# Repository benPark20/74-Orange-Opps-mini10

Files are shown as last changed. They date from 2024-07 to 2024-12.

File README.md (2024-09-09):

# 74-Orange-Opps

## We are Team 74 of mini FRC, the Orange Opps.

Shooting Speaker

Our rookie season 2024 was great! You can watch [the stream of the event](https://www.youtube.com/watch?v=baMjMV4FzJ8) but it is really long so i would reccomend if you want to see to watch [match 17](https://youtu.be/baMjMV4FzJ8?t=8170) (*we are the middle one on blue alliance*). Here are some of our accomplishments at Mini FRC 10:
- Our alliance made it to the semifinals in the losers bracket in a double elimintaion tournement (*That's 3rd Place!*),
- We managed to be the first, and one of the only, team to successfully climb on the stage,
- and we had the cleanest looking robot ~~*biased*~~.

## Design

We designed our robot heavily off of the robot that our team's team had competed and made worlds with for regular, full-sized FRC. Our workflow was in OnShape so you can [easily view and download/3D print CAD here](https://cad.onshape.com/documents/561065ee11688eb6314d06ba/w/829a4e28d8331633d6eed549/e/7dac9a85c5c0d4fed6ff8528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).

Robot CAD
*pretend that those are mechanum wheels (it's a pain to deal with them in cad)*

## Assembly

Assembly of the robot was fairly straight forward since we CAD to go off of, but we did need a lot of parts and a lot of testing testing shooter.
This is a quick BOM, the total cost adds up to around $70 and it was split between the four people on our team
| Item | Quantity |
| :--- | :---: |
| ESP32 | 1 |
| Alfredo NoU2 | 1 |
| [9V Battery](https://www.alfredosys.com/news/fun-facts-about-batteries/)* | 1 |
| Mechanum Wheels | 4 |
| TT Motor + gearbox| 4 |
| TT Motor | 2 |
| n20 Motor | 2 |
| 50g servo | 1 |
| Grip Tape | 1 |
| Wires | 1 |

## Code

Our code is based in Arduino IDE and runs on an ESP32 connected to a [NoU2 board](https://www.alfredosys.com/products/alfredo-nou2/) though we have plans to upgrade to a NoU3 when it comes out. I have been working with the code to implement an ultrasonic sensor that can detect how far away our robot is from the stage so that it can automatically aim and shoot from any point on our wing with no obstruction.

## How can you do the same

This was only possible with the help of [Alfredo Systems](https://www.alfredosys.com) and the wonderful program that they are running. I you want to just buy parts and make your own then go for it, but if you are wanting to hold a competition for you and your community then reach out to them on their website! They provide all the resources you would ever need to hold one of these. It is a great outreach opportunity and really a fun event all around.

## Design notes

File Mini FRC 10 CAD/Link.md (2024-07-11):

# [Link to OnShape Document](https://cad.onshape.com/documents/561065ee11688eb6314d06ba/w/829a4e28d8331633d6eed549/e/dabec9b53802dcae05636834)

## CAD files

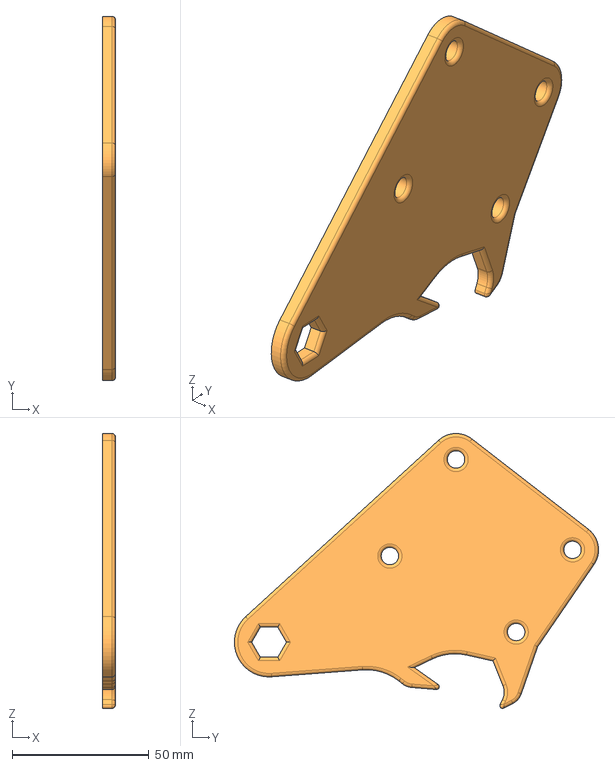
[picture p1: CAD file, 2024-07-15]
Mini FRC 10 CAD/Master Part Studio - Plate 1.step
4.76 x 133.3 x 100.7 mm

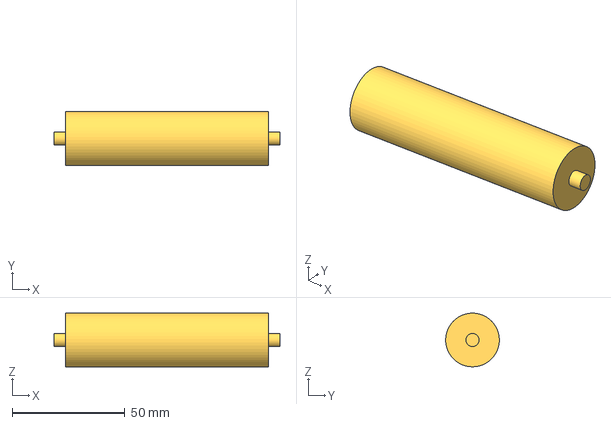
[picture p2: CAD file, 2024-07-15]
Mini FRC 10 CAD/Master Part Studio - Roller 1.step
100.4 x 23.9 x 23.9 mm

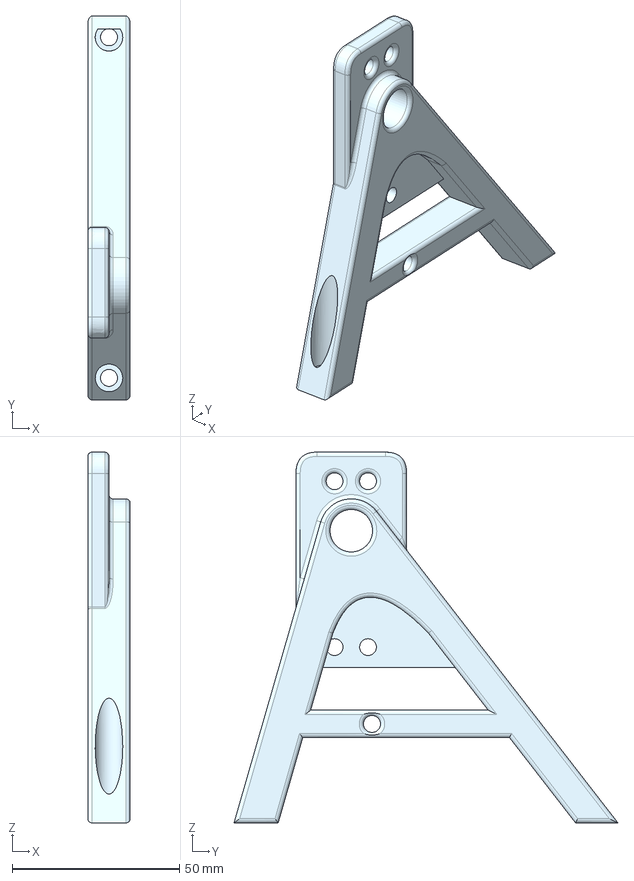
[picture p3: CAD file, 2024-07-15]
Mini FRC 10 CAD/Master Part Studio - A-Frame 2.step
12.7 x 114.8 x 110.8 mm

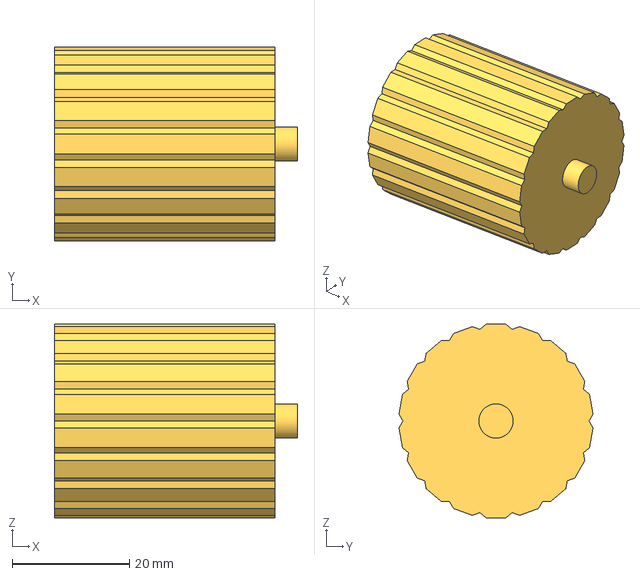
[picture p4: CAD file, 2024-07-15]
Mini FRC 10 CAD/Master Part Studio - Flywheel.step
41.5 x 33.1 x 33.0 mm

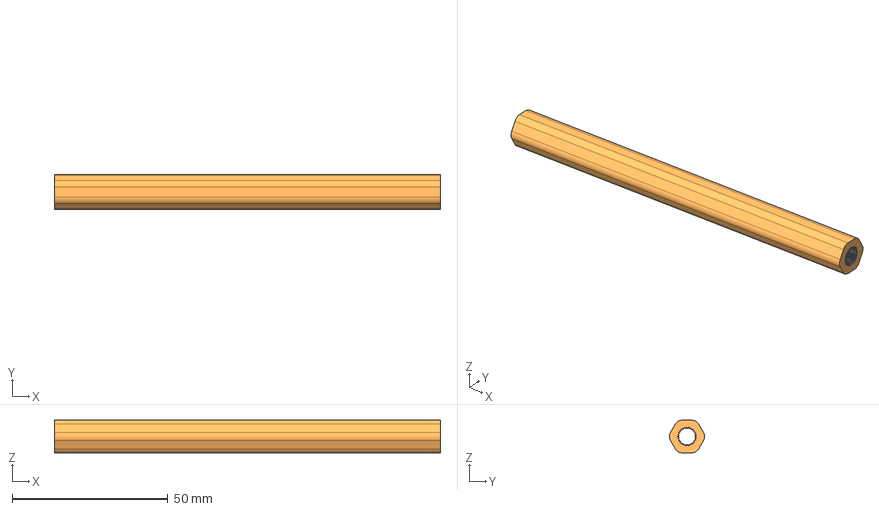
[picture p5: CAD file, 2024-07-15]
Mini FRC 10 CAD/Master Part Studio - Hex.step
123.9 x 11.3 x 10.5 mm

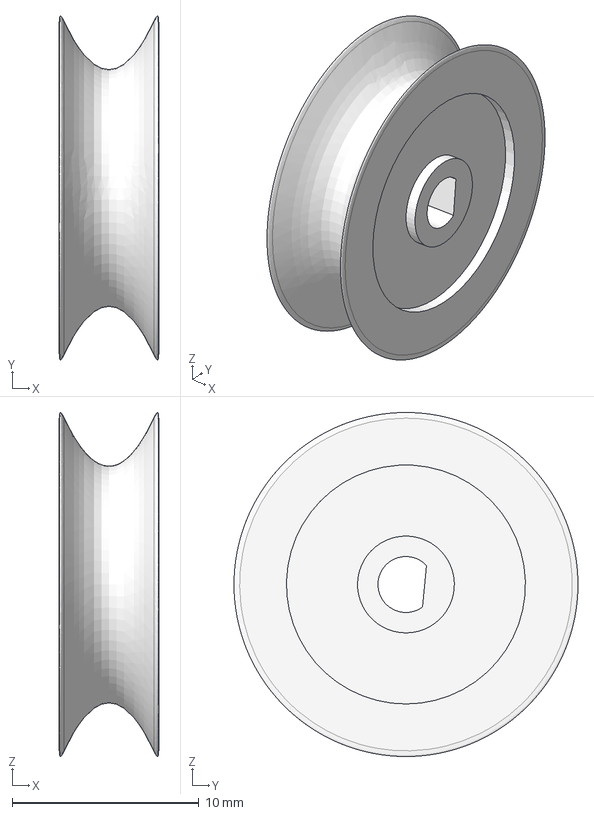
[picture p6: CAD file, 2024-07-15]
Mini FRC 10 CAD/Master Part Studio - Intake Pulley.step
5.33 x 18.4 x 18.4 mm

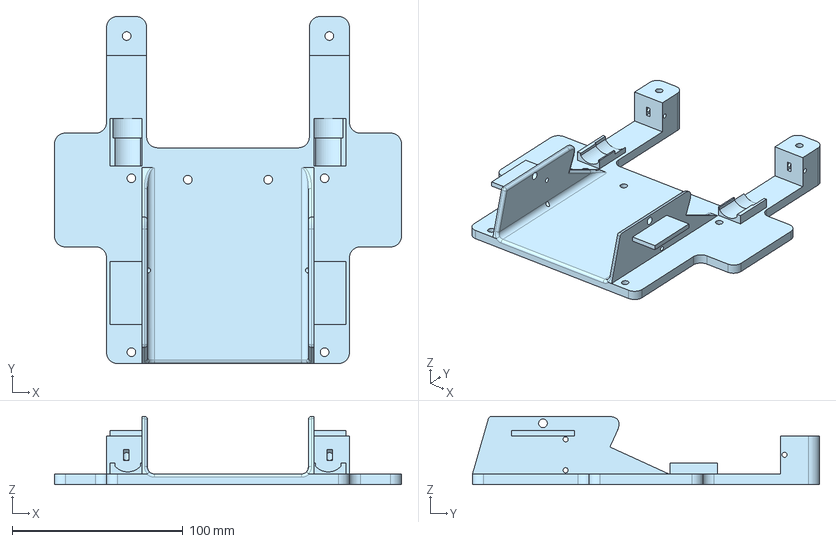
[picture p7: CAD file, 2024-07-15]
Mini FRC 10 CAD/Master Part Studio - Chassis.step
203.2 x 203.2 x 40.0 mm

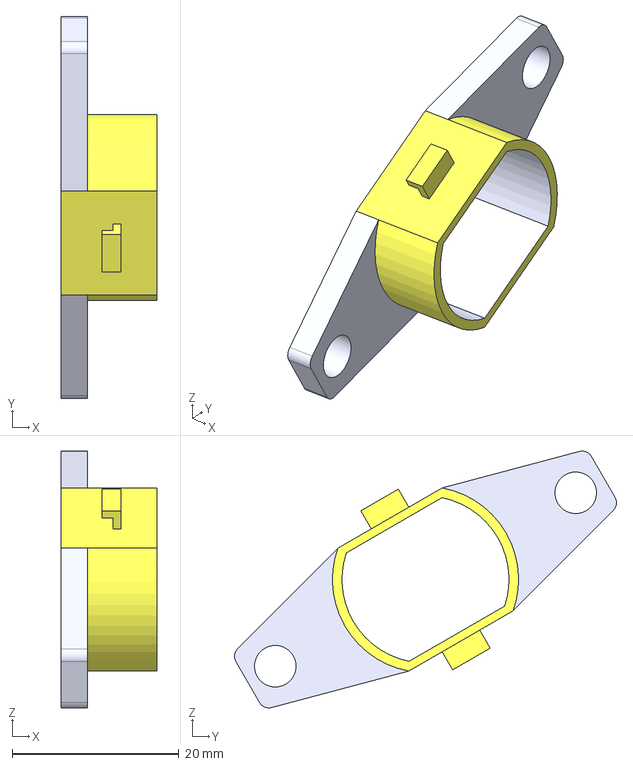
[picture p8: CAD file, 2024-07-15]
Mini FRC 10 CAD/Master Part Studio - Motor-Mount.step
11.5 x 45.8 x 30.8 mm

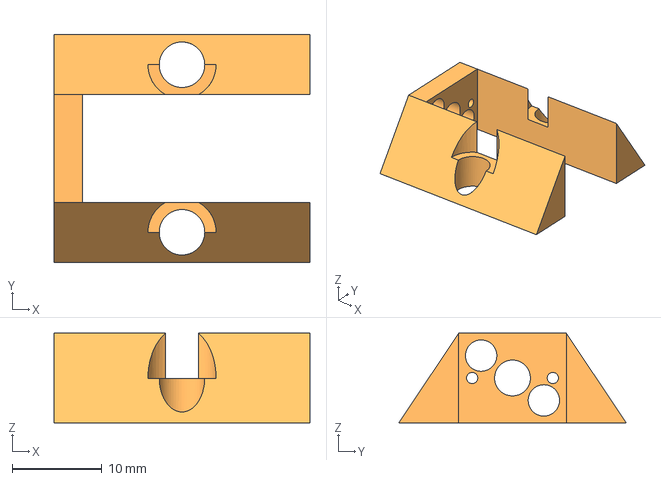
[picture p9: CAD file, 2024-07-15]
Mini FRC 10 CAD/Master Part Studio - Intake Motor Mount.step
28.6 x 25.4 x 10.0 mm

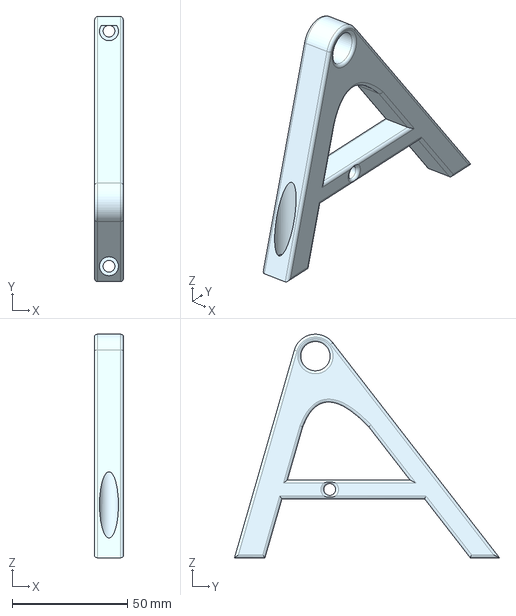
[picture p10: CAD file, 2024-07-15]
Mini FRC 10 CAD/Master Part Studio - A-Frame 1.step
12.7 x 114.8 x 96.9 mm

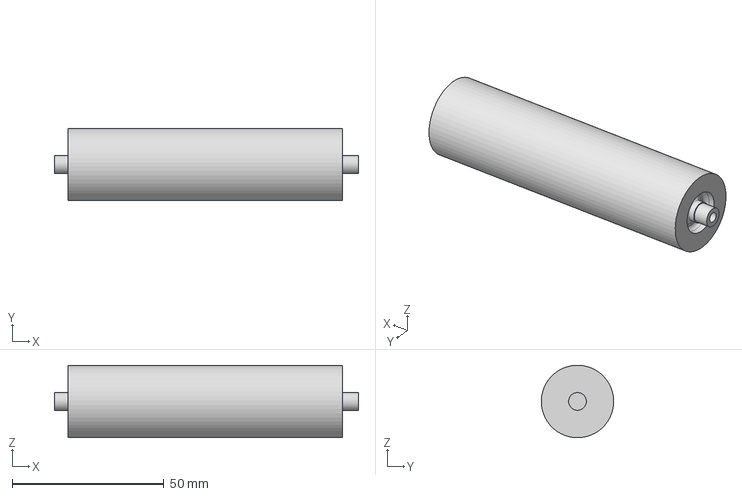
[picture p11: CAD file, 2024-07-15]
Mini FRC 10 CAD/Master Part Studio - Roller 2.step
100.2 x 23.9 x 23.9 mm

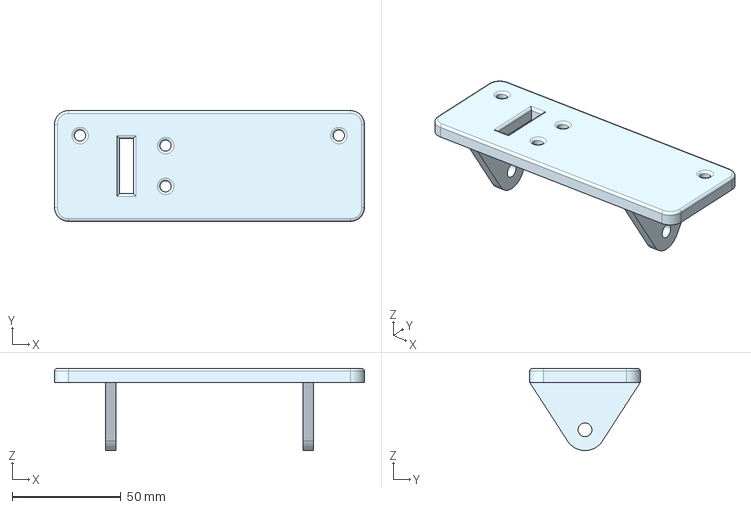
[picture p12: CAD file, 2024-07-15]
Mini FRC 10 CAD/Master Part Studio - Intake Plate.step
142.2 x 50.8 x 37.7 mm

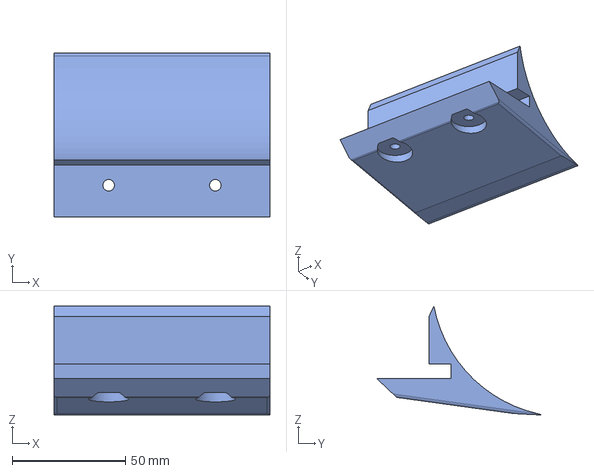
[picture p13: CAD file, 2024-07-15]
Mini FRC 10 CAD/Master Part Studio - Scoop.step
95.2 x 72.5 x 48.0 mm

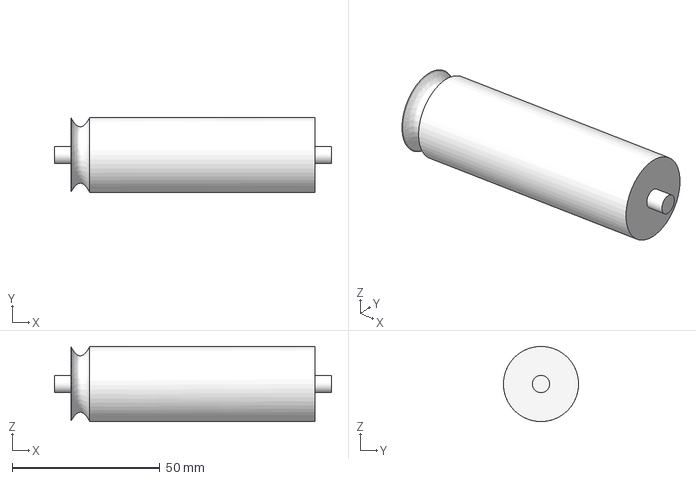
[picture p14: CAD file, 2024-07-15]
Mini FRC 10 CAD/Master Part Studio - Intake Roller.step
93.7 x 25.4 x 25.4 mm

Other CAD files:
Mini FRC 10 CAD/Master Part Studio - Plate 2.step
Mini FRC 10 CAD/Master Part Studio - Hex Spacer.step
Mini FRC 10 CAD/Intake+drivetrain V1.stl

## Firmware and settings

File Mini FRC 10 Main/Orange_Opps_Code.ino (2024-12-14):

#include <PestoLink-Receive.h>
#include <Alfredo_NoU2.h>
#include <NewPing.h>

// Button definitions
#define BUTTON_BOTTOM 0
#define BUTTON_RIGHT 1
#define BUTTON_LEFT 2
#define BUTTON_TOP 3
#define LEFT_BUMPER 4
#define RIGHT_BUMPER 5
#define LEFT_TRIGGER 6
#define RIGHT_TRIGGER 7
#define MID_RIGHT 8
#define MID_LEFT 9
#define L_PRESS 10
#define R_PRESS 11
#define D_UP 12
#define D_DOWN 13
#define D_LEFT 14
#define D_RIGHT 15

// Motor and servo definitions
NoU_Motor frontLeftMotor(1); 
NoU_Motor frontRightMotor(2);
NoU_Motor rearLeftMotor(3);
NoU_Motor rearRightMotor(4);
NoU_Motor indexerMotor(5); // Intake/indexer motor
NoU_Motor shooterMotor(6); // Shooter motor
NoU_Servo servo(1);        // Aiming servo

// Drivetrain setup
NoU_Drivetrain drivetrain(&frontLeftMotor, &frontRightMotor, &rearLeftMotor, &rearRightMotor);

// Distance sensor setup
#define TRIGGER_PIN 25
#define ECHO_PIN 26
#define MAX_DISTANCE 400
NewPing sonar(TRIGGER_PIN, ECHO_PIN, MAX_DISTANCE);

// Variables
int distance = 0;         // Distance measured to subwoofer
int measurements = 0;       // Number of measurements taken
int servoAngle = 0;         // Servo angle for aiming
float indexerThrottle = 0;
float shooterThrottle = 0;

// Time tracking for auto mode
long AUTO_START_TIME = 0;
long SHOOTER_START_TIME = 0;

// Enum for robot states (manual or auto mode)
enum State { MANUAL, AUTO };
State ROBOT_STATE;

void setup() {
  PestoLink.begin("Clementiny");  // Name your robot here
  Serial.begin(9600);
  Serial.println("Start");
  
  // Invert motors if necessary
  frontLeftMotor.setInverted(true);
  frontRightMotor.setInverted(false);
  rearLeftMotor.setInverted(true);
  rearRightMotor.setInverted(false);
  shooterMotor.setInverted(true);
  indexerMotor.setInverted(false);

  // Initialize robot state to manual
  ROBOT_STATE = MANUAL;
}

void loop() {
  // Update connection status and handle robot states
  if (PestoLink.update()) {
    if (ROBOT_STATE == MANUAL) {
      handleManualMode();
      PestoLink.print("Teleop", "0x32a852");
    } else {
      handleAutoMode();
      PestoLink.print("Auto", "0x36a0d1" );
    }
    RSL::setState(RSL_ENABLED);
  } else {
    RSL::setState(RSL_DISABLED);
  }
  // No need to modify this
  RSL::update();
}

// Handle manual driving and shooting
void handleManualMode() {

  // Start auto mode if button is pressed
  if (PestoLink.buttonHeld(MID_LEFT)) {
    ROBOT_STATE = AUTO;
    AUTO_START_TIME = millis();
    return;
  }

  // Driving controls
  float xVelocity = PestoLink.getAxis(0);
  float yVelocity = -PestoLink.getAxis(1);
  float rotation = PestoLink.getAxis(2);
  drivetrain.holonomicDrive(xVelocity, yVelocity, rotation);

  // Servo adjustment based on distance to subwoofer (when button pressed)
  if (PestoLink.buttonHeld(BUTTON_LEFT)) {
    updateDistanceAndServo();
  }

  // Manual servo control
  manualServoControl();

  // Motor control for indexer and shooter
  handleIndexerAndShooter();
  
  // Apply motor throttle
  indexerMotor.set(indexerThrottle);
  shooterMotor.set(shooterThrottle);

  // Apply Servo Angle
  servo.write(servoAngle);
}

// Handle servo control using distance sensor
void updateDistanceAndServo() {
  if (measurements < 50) {
    int distance = sonar.ping_cm();// Get distance in cm
    int trash = sonar.ping_cm();
    measurements++;
    
    if (distance != 0.00) {
      // Tune distance offset as needed
      distance += -2;
      if(distance <= 0){distance = 0;}

      // Set servo angle based on distance using a regression function or lookup table
      servoAngle = calculateServoAngleFromDistance(distance);  // Use regression data here
      char buffer[64];
      sprintf(buffer, "Distance: %i || Angle: %i", distance, servoAngle);
      PestoLink.printToTerminal(buffer);
    }
  }
}

// Function to calculate servo angle from distance using regression model
int calculateServoAngleFromDistance(float distance) {

  int x = distance;
  float a = -7705.458;
  float b = 0.97141;
  float c = -104.09;
  float d = 97.8772;

  float angle = (a * (b / (x - c)) + d);

  float A = 1.13565;
  float B = 0.302267;
  float C = -1.58807;
  float D = -0.128382;

  angle += (A * cos(B * x + C) + D);
  
  // Clamp the angle to a valid range for your servo
  if (angle < 0) angle = 0;
  if (angle > 180) angle = 180;

  return angle;
}


// Manual servo control using joystick or buttons'
int lastA = -1;

void manualServoControl() {
  if (PestoLink.buttonHeld(D_DOWN) && servoAngle > 0) {
    servoAngle -= 1;
    delay(100);
    char buffer[64];
    sprintf(buffer, "Angle: %i", servoAngle);
    PestoLink.printToTerminal(buffer);
  }
  if (PestoLink.buttonHeld(D_UP) && servoAngle < 180){
    servoAngle += 1;
    delay(100);
    char buffer[64];
    sprintf(buffer, "Angle: %i", servoAngle);
    PestoLink.printToTerminal(buffer);
  }
  if(PestoLink.buttonHeld(BUTTON_BOTTOM)){
    servoAngle = 120;//amp
    PestoLink.printToTerminal("Amp Angle");
  }
  else if(PestoLink.buttonHeld(BUTTON_RIGHT)){
    servoAngle = 80;//pass
    PestoLink.printToTerminal("Passing Angle");
  }
  else if(PestoLink.buttonHeld(R_PRESS)){
    updateDistanceAndServo();
  }

  if(servoAngle != lastA){
    lastA = servoAngle;
  }
}

// Handle the indexer and shooter motors
void handleIndexerAndShooter() {
  // Control the indexer (intake) motor
  if (PestoLink.buttonHeld(LEFT_BUMPER)) {
    indexerThrottle = 1;  // Intake forward
    servoAngle = 0;
    PestoLink.printToTerminal("Intaking. . .");
  } else if (PestoLink.buttonHeld(LEFT_TRIGGER)) {
    indexerThrottle = -1; // Intake reverse
  } else {
    indexerThrottle = 0;  // Stop intake
  }
  
  // Control the shooter motor
  if (PestoLink.buttonHeld(RIGHT_TRIGGER)) {
    shooterThrottle = 1; // Spin shooter motor to shoot
    SHOOTER_START_TIME = millis();
    updateDistanceAndServo();
  } else if(PestoLink.buttonHeld(RIGHT_BUMPER)){
    servoAngle = 25;
    shooterThrottle = 1;
    SHOOTER_START_TIME = millis();
  } else if(PestoLink.buttonHeld(BUTTON_TOP)){
    shooterThrottle = 1;
    SHOOTER_START_TIME = millis();
  } else if(PestoLink.buttonHeld(LEFT_BUMPER) || PestoLink.buttonHeld(LEFT_TRIGGER)){
    shooterThrottle = -1;
  } else {
    shooterThrottle = 0;
  }

  // Reset measurments
  if(PestoLink.buttonHeld(BUTTON_LEFT)){
    measurements = 0;
  }

  // Timing for indexer based on shooting
  handleShooterTiming();
}

// Handle timing for shooter and indexer motors
void handleShooterTiming() {
  if (SHOOTER_START_TIME != 0 ) {
    unsigned long currentTime = millis();
    unsigned long elapsedTime = currentTime - SHOOTER_START_TIME;

    if (elapsedTime > 100 && elapsedTime <= 1200) {
      indexerThrottle = 1;  // Run indexer during shoot
      shooterThrottle = 0.7;
      PestoLink.printToTerminal("Shots Fired!");
    } else if (elapsedTime > 1200 && elapsedTime < 1400) {
      measurements = 0;
      shooterThrottle = -1;
    } else if (elapsedTime >= 1400) {
      resetMotors();
      SHOOTER_START_TIME = 0; // Reset after the shoot sequence
      return;
    }
  }
}

float TSA = 0;
// Handle auto mode actions
void handleAutoMode() {
  if (PestoLink.buttonHeld(MID_RIGHT)) {
    ROBOT_STATE = MANUAL;
    return;
  }
  TSA = (millis() - AUTO_START_TIME);
    if(TSA < 14000){
      if(TSA < 1000){ //aim and spin up shooter
        servo.write(33);//subwoofer angle
        shooterMotor.set(1);
      }
      if(TSA > 1000 && TSA < 1500){ //shoot
        indexerMotor.set(1);
      }
      if(TSA > 1500 && TSA < 2000){//reset motor
        resetMotors();
      }
      if(TSA > 2100 && TSA < 2200){//reset servo
        servo.write(0);
      }
      if(TSA > 2500 && TSA < 4000){//intake
        indexerMotor.set(1);
        shooterMotor.set(-1);
        if(TSA > 2600 && TSA < 3100/*change for distance*/){
          drivetrain.arcadeDrive(1, 0);
        } else{
          drivetrain.arcadeDrive(0, 0);
        }
      }
      if(TSA > 4000 && TSA < 4250){//reset motor
        resetMotors();
      }
      if(TSA > 4000 && TSA < 4500/*change for distance*/){//drive to subwoofer
        drivetrain.arcadeDrive(-1, 0);
      }
      if(TSA > 4500 && TSA < 5600){//stop
        drivetrain.arcadeDrive(0,0);
      }
      if(TSA > 5600 && TSA < 7000){ //aim and spin up shooter
        drivetrain.arcadeDrive(0, 0);
        servo.write(33);//subwoofer angle
        shooterMotor.set(1);
      }
      if(TSA > 7000 && TSA < 7500){ //shoot
        indexerMotor.set(1);
      }
      if(TSA > 7500 && TSA < 8000){//reset motor
        resetMotors();
      }
      if(TSA > 8000){//reset servo
        servo.write(0);
      }
    }
    else {
      drivetrain.arcadeDrive(0, 0);
      return;      
    }
}

// Reset motors (shooter and indexer)
void resetMotors() {
  shooterMotor.set(0);
  indexerMotor.set(0);
}

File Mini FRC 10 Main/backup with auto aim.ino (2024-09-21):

/*
TIPS FOR TUNING!
when axle is positioned right
Servo minimum is -20
Servo maximum is 130
Motors dont work until 0.6 to 0.7

*/


#include <PestoLink-Receive.h>
#include <Alfredo_NoU2.h>
#include <NewPing.h>

// If your robot has more than a drivetrain and one servo, add those actuators here 
NoU_Motor frontLeftMotor(1); 
NoU_Motor frontRightMotor(2);
NoU_Motor rearLeftMotor(3);
NoU_Motor rearRightMotor(4);
NoU_Motor indexerMotor(5);
NoU_Motor shooterMotor(6);
NoU_Servo servo(1);

// This creates the drivetrain object, you shouldn't have to mess with this
NoU_Drivetrain drivetrain(&frontLeftMotor, &frontRightMotor, &rearLeftMotor, &rearRightMotor);

//distance sensor
#define TRIGGER_PIN 25
#define ECHO_PIN 26
#define MAX_DISTANCE 400

NewPing sonar(TRIGGER_PIN, ECHO_PIN, MAX_DISTANCE);

float distance;
float TSA;
int measurements;
// This lets us easily keep track of whether the robot is in auto mode or not.
// Experiment with adding more modes!
enum State { MANUAL, AUTO };

// These are the buttons we look for.
int AUTO_START_BUTTON = 8;
int AUTO_CANCEL_BUTTON = 9;

// This stores the time at which we started auto mode. This lets us keep track of how long we've been in auto mode for.
long AUTO_START_TIME = 0;
long SHOOTER_START_TIME = 0;
State ROBOT_STATE;

void setup() {
  //EVERYONE SHOULD CHANGE "ESP32 Bluetooth" TO THE NAME OF THEIR ROBOT
  PestoLink.begin("CallingAllBluds");
  Serial.begin(9600);
  // If a motor in your drivetrain is spinning the wrong way, change the value for it here from 'false' to 'true'
  frontLeftMotor.setInverted(true);
  frontRightMotor.setInverted(false);
  rearLeftMotor.setInverted(true);
  rearRightMotor.setInverted(false);

  // No need to mess with this code
  RSL::initialize();
  RSL::setState(RSL_ENABLED);
  ROBOT_STATE = MANUAL;
}

void loop() {
  // Here we define the variables we use in the loop
  float indexerThrottle = 0;
  float shooterThrottle = 0.1; //this needs tuning
  int servoAngle = 90;
  int AutoAngle;

  //When PestoLink.update() is called, it returns "true" only if the robot is connected to phone/laptop  
  if (PestoLink.update()) {
    if (ROBOT_STATE == MANUAL) {
      // We only want to check manual controls if we're in manual mode!
      if (PestoLink.buttonHeld(AUTO_START_BUTTON)) {
        // If the auto mode button is pressed, we should switch to auto mode.
        ROBOT_STATE = AUTO;
        AUTO_START_TIME = millis();
        return; // We don't want to check the manual controls - we just switched to auto mode! This immediately restarts the loop.
      }
      float xVelocity = PestoLink.getAxis(0) * 1;
      float yVelocity = -PestoLink.getAxis(1) * 1;
      float rotation = PestoLink.getAxis(2) * 1;

      drivetrain.holonomicDrive(xVelocity, yVelocity, rotation);

      // Here we decide what the servo angle will be based on if a button is pressed ()

      // Servo Code:
      if (PestoLink.buttonHeld(12)) {
        servoAngle = 130; //climber up angle/amp
        servo.write(servoAngle);
      } else if (PestoLink.buttonHeld(13)) {
        servoAngle = 29; //subwoofer angle
        servo.write(servoAngle);
      } else if (PestoLink.buttonHeld(15)) {
        servoAngle = 53; //podium
        servo.write(servoAngle);
      } else if (PestoLink.buttonHeld(2)) {
        if(measurements < 50){
          distance = sonar.ping()/10;
          measurements++;
          Serial.println(distance);
          if(distance != 0.00){
            distance += 20; //comment out this line for no subwoofer. 20cm = 8 inches
            AutoAngle = distance/5;
            if(distance > 0.1){
              shooterThrottle = -1;
              AutoAngle = distance/5;
              servoAngle = AutoAngle;
              servo.write(servoAngle);
            }
          }
        }
      }
      //Manual Servo Control
      
      if ((PestoLink.getRawAxis(3)) > 230){
        if (servo.getDegrees() > 0){
          servo.write(servo.getDegrees() - 0.001);
        }
      }

      // Motor Code:
      if (PestoLink.buttonHeld(4)) {
        indexerThrottle = 1;
        servo.write(-0);
      } else if (PestoLink.buttonHeld(6)) {
        indexerThrottle = -1;
      } 
      else {
        indexerThrottle = 0;
      }
      
      if (PestoLink.buttonHeld(5)) {
        shooterThrottle = 1;
      } else if (PestoLink.buttonHeld(0)) {
        shooterThrottle = -1;
        SHOOTER_START_TIME = millis();
      } else if (PestoLink.buttonHeld(7)){
        if(measurements < 50){
          distance = sonar.ping()/10;
          measurements++;
          Serial.println(distance);
          if(distance != 0.00){
            distance += 20; //comment out this line for no subwoofer. 20cm = 8 inches
            AutoAngle = distance/5;
            if(distance > 0.1){
              shooterThrottle = -1;
              AutoAngle = distance/5;
              servoAngle = AutoAngle;
              servo.write(servoAngle);
            }
          }
        }
        shooterThrottle = -1;
        SHOOTER_START_TIME = millis();
      } else if(PestoLink.buttonHeld(3)){
        measurements = 0;
      } else if(PestoLink.buttonHeld(1)){
        //automatic amp
      } else {
        if (PestoLink.buttonHeld(4) || PestoLink.buttonHeld(6)){
          shooterThrottle = 0.8;
        } else{
          shooterThrottle = 0;
        }
      }
      
      // Handle indexer motor timing based on SHOOTER_START_TIME
      if (SHOOTER_START_TIME != 0) {
        unsigned long currentTime = millis();
        unsigned long elapsedTime = currentTime - SHOOTER_START_TIME;
        if (elapsedTime > 1 && elapsedTime <= 1250) {
          indexerThrottle = 1;
        } else if (elapsedTime > 1500) {
          SHOOTER_START_TIME = 0; // Reset SHOOTER_START_TIME after the interval
          measurements = 0;
        }
      }

      indexerMotor.set(indexerThrottle);
      shooterMotor.set(shooterThrottle);
    } else {
      // We're in auto mode, so we should handle auto mode.
      if (PestoLink.buttonHeld(AUTO_CANCEL_BUTTON)) {
        // Check to see if we should cancel auto mode.
        ROBOT_STATE = MANUAL;
        return;
      }
      TSA = (millis() - AUTO_START_TIME);
      if (TSA < 1000) {
        servo.write(33);
        shooterMotor.set(-1);
        SHOOTER_START_TIME = millis();
      } 
      else if((TSA > 999) && (TSA < 3000)){
        if(TSA > 2750) {
          servo.write(-20);
          drivetrain.arcadeDrive(-1, 0);
          indexerMotor.set(1);
          shooterMotor.set(1);
        } else {
          drivetrain.arcadeDrive(1, 0);
          indexerMotor.set(0);
          shooterMotor.set(0);
        }
      } else if((TSA > 3499) && (TSA < 6000)){
        servo.write(33);
        shooterMotor.set(-1);
        SHOOTER_START_TIME = millis();
      }
      else {
        drivetrain.arcadeDrive(0, 0);
        ROBOT_STATE = MANUAL;
        return;
      }
    }

    RSL::setState(RSL_ENABLED);
  } else {
    RSL::setState(RSL_DISABLED);
  }
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

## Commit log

2024-07-17 Update and rename Drivetrain.cpp to Drivetrain.ino
2024-09-18 Fix auto and auto aim
    [Orange_Opps_Code.ino]
